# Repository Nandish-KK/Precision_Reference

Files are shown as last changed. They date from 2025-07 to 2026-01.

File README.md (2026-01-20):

#  2.5V Precision Reference

A compact 2.5V precision voltage reference module, ideal for use as a standalone reference when building analog circuit prototypes or for verifying the accuracy of your multimeter’s voltage range over time.

## Prototyping and Testing
The design required a low voltage source to make the Reference module as compact as possible. A CR2032 coin cell at 3V is the ideal candidate.
This requirement turns into a design constraint as the minimum operating voltage stated in the datasheet for the REF03 is 4.5V. The REF03 is a Low-Dropout
type Reference and is the best option to design a voltage reference due to its extremly low Temperature coefficient (10-50 ppm/C) and requires minimum passive components to operate.

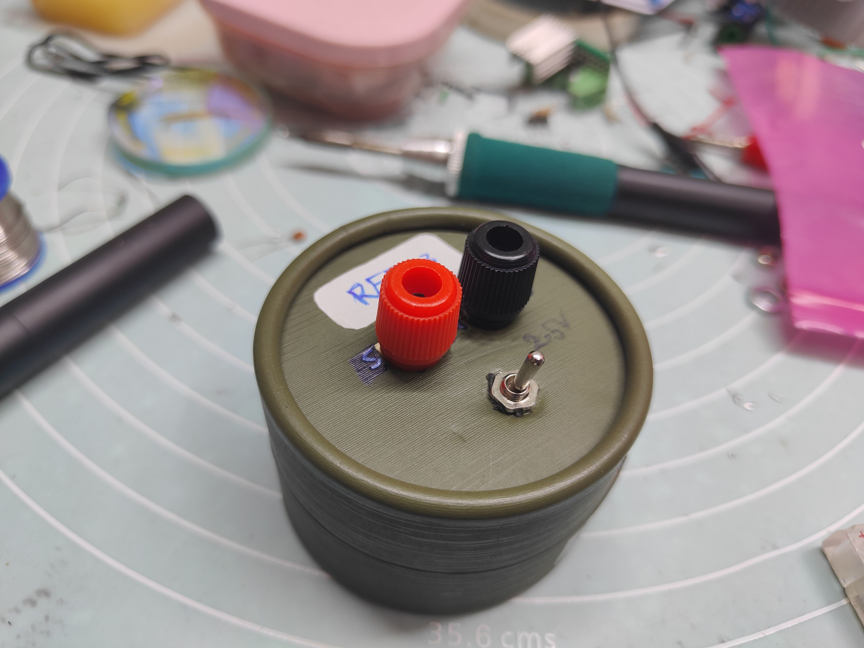
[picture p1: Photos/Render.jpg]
Prototype


Proto_board

### Charge pump
In order to generate a voltage that is sufficient to drive the REF03 above the minimum operating voltage a charge pump topology is implemented.
The charge pump consists of a variable frequency oscillator and a voltage doubler circuit. The oscillator is constructed using an SN74 logic inverter with
hysteresis and an RC feedback network. At 3V input, the circuit can generate a maximum of 5.6V but drops drastically depending on the load.
The quiescent current of the REF03 is around 1 mA, which also gives a bit of headroom to even sink some current into the DUT. 

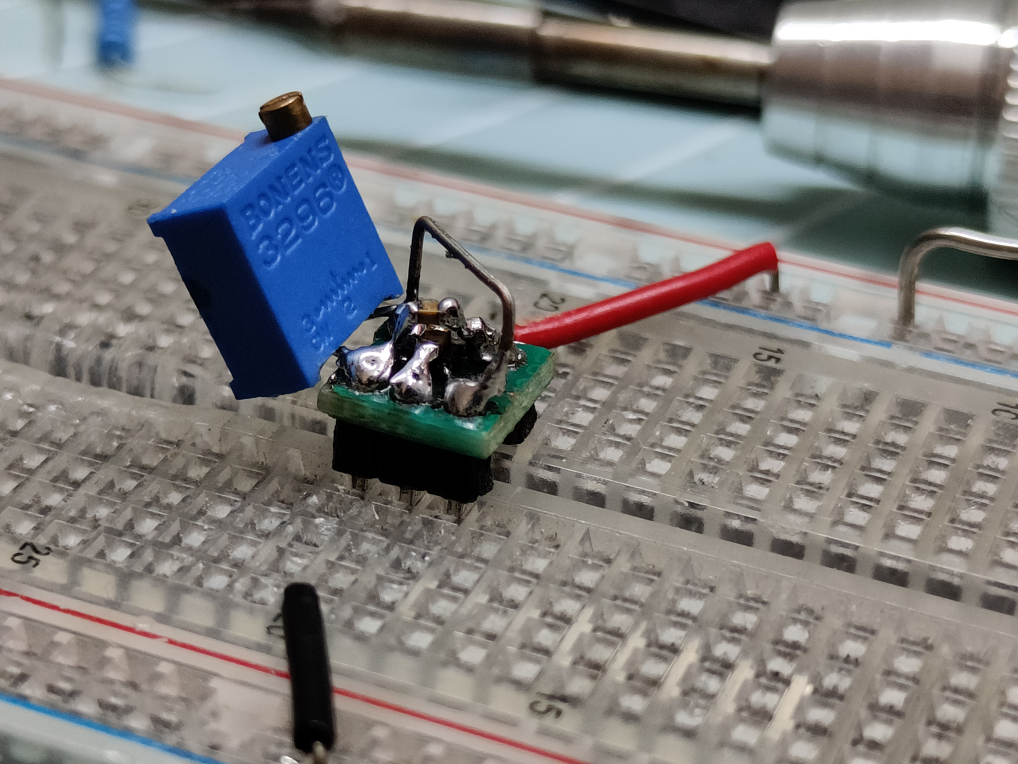
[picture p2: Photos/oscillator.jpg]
osc


Oscillator: SN74LVC2G14DBV sot23-6 soldered with passives on a proto pcb.

### Testing

The following tests are performed with a wide bandwidth. You can see some high-frequency noise along with voltage ripples at the charge pump output (with REF03 connected). After further testing, it seems like the ripples are generated from the oscillator.
The SN74LVC2G14DBV has a fast rising edge of about 4ns; this, combined with Schmitt trigger action and the board's parasitics, results in a ringing behavior at the output. This high-frequency component seems to bypass even the REF03 and appears at the reference voltage. Implementation of an additional filtering circuit might be necessary. Another option is to find an inverter with a slower rise time.

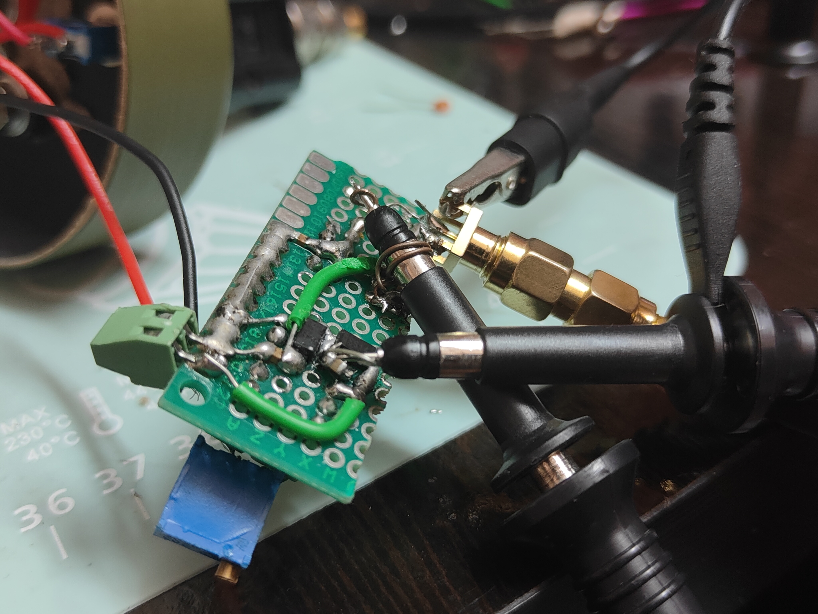
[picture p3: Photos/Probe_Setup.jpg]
probe_setup


Tested the reference output with coax to make sure the noise isn't from a background source. The other two channels are connected to the charge pump output and the oscillator output.

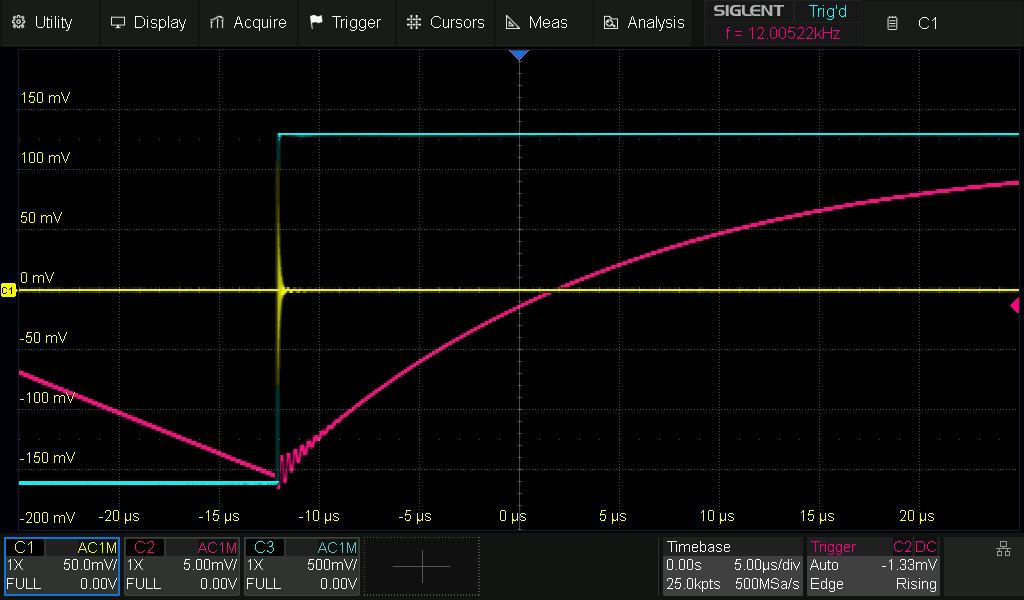
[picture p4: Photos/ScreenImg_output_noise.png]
High_frequency_Noise


- Yellow : Reference Output
- Pink :   Charge pump Output
- Blue :   Oscillator  Output

#### No Load condition

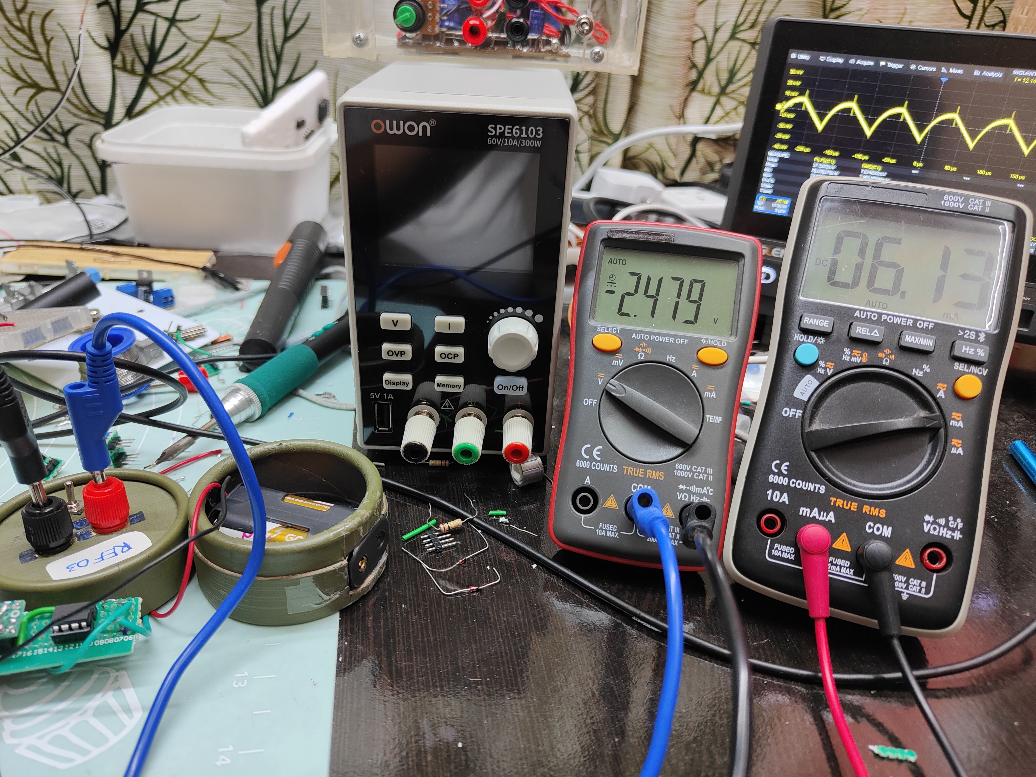
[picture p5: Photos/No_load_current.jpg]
Setup1

The voltmeter isn't accurate and is used to observe voltage drops with and without load.

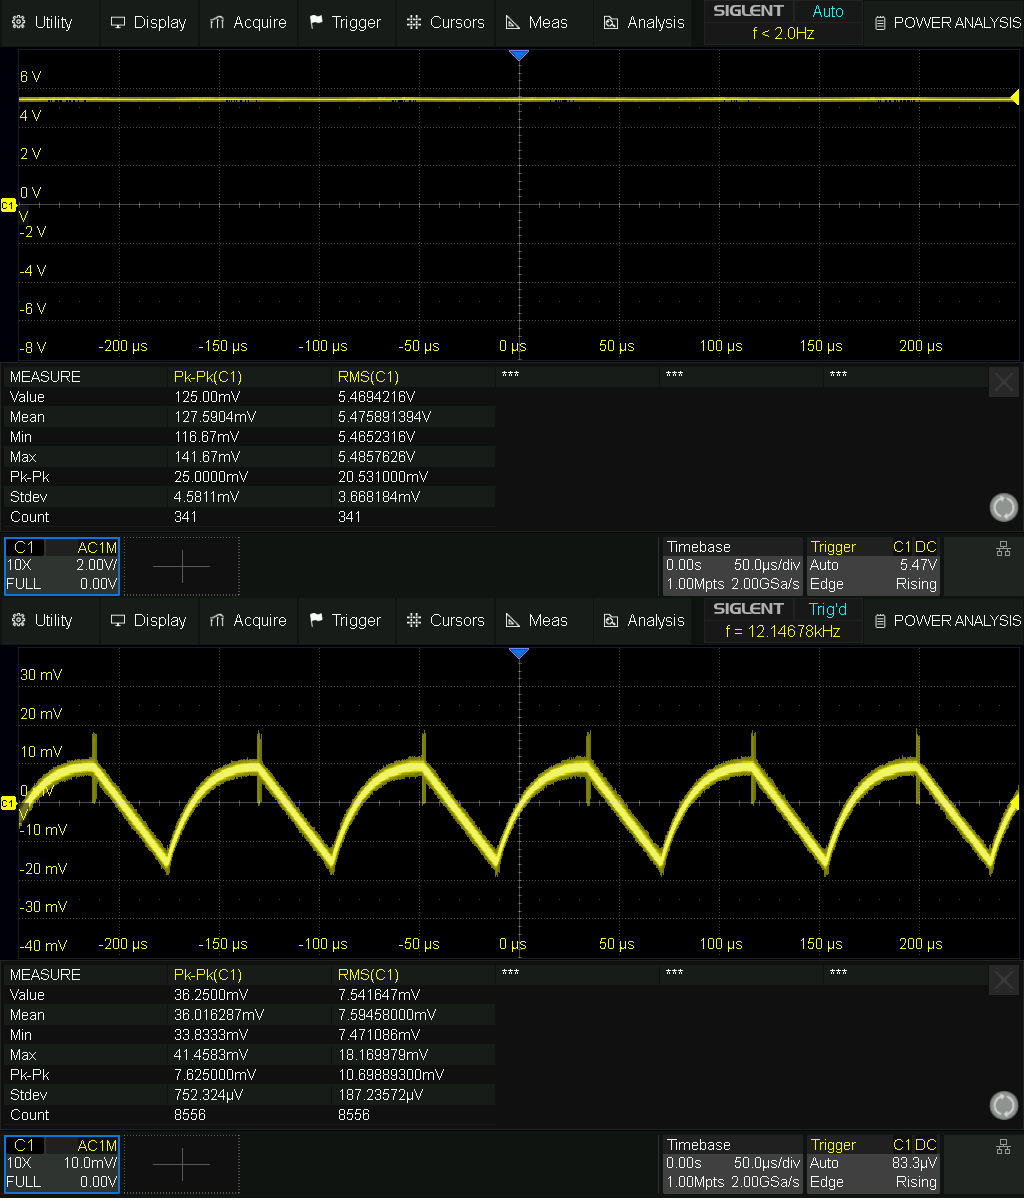
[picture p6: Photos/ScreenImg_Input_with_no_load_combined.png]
Charge_pump_out_no_load


With a high-impedance load like a multimeter (essentially no load) attached to the output of the REF03, the voltage is quite stable and exhibits minimal ripple.
The output voltage is around 5.47V with a ripple of 36.25mV peak-to-peak (7.54mV RMS). The setup also draws around 6mA, which is quite high. Since the REF03 draws 1-2 mA, the additional current should be consumed by the oscillator. This is not a good circuit to leave ON for a long time; it will drain the CR2032 in a day or two. Make sure to turn off the module with the toggle switch after use to prevent it from going completely dead. 

#### 10mA Load 
The charge pump output voltage seems to drop significantly if the REF03 starts to sink current to the load. The REF03 is rated to sink up to 24mA, but this much current will render my simple charge pump setup useless. I did end up testing the current sink capability of the prototype using a variable potentiometer, and it seems like the voltage starts to drop around 16mA of total current draw. This indicates that the prototype PCB was able to sink 10mA from the REF03 (remember that the circuit draws 6mA at idle). The voltage dropping trend was observed using a 3.5-digit multimeter, and results may vary with more accurate meters.

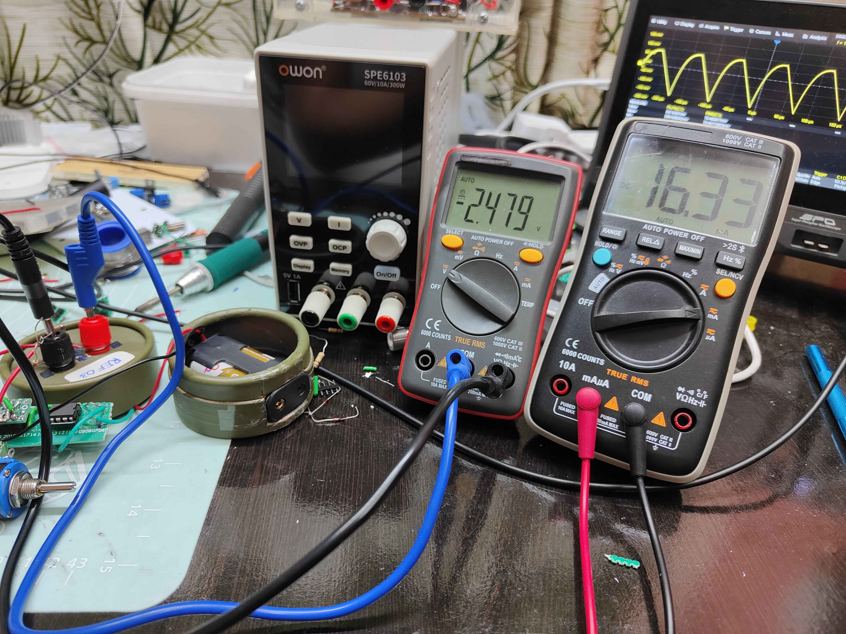
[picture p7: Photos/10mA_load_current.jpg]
Setup2

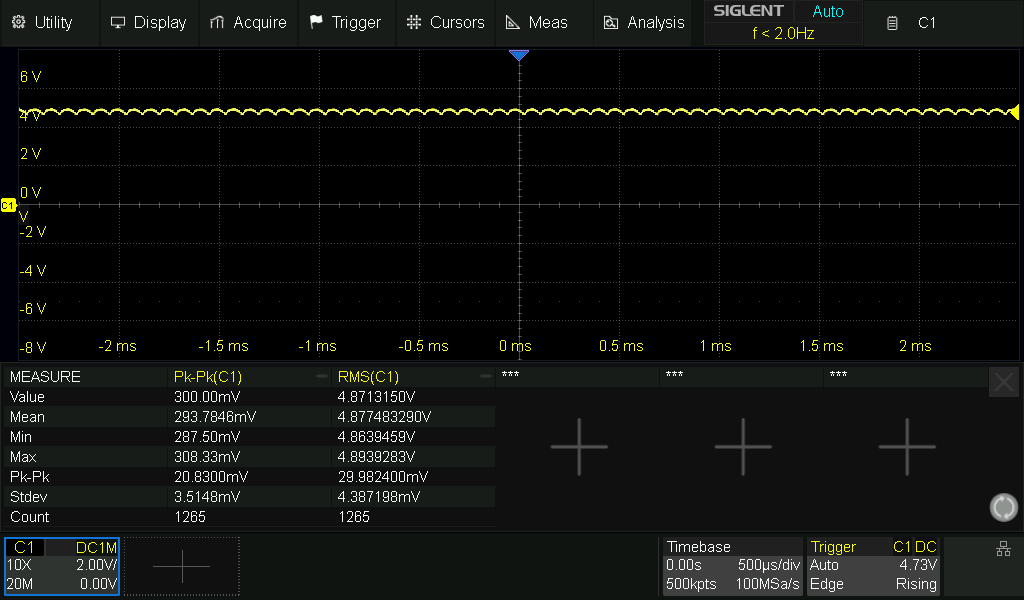
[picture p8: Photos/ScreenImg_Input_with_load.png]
Charge_pump_out_10ma_load


While sinking 16mA of total current, the charge pump output drops to around 4.87 volts while also exhibiting some ripple characteristics. The ripple is around 300mV peak-to-peak with a frequency that corresponds to the charge pump switching frequency. Thankfully, the ripple doesn't reflect on the output of the REF03. Note that these ripples can be minimized with appropriate capacitance.

## Output Stability

Currently, I don't own a precision multimeter, which makes it harder to measure how stable the output voltage really is. What I do own is a DSO with a 12-bit ADC (SDS800X), and it seems to read the voltage accurately up to 4 digits easily. The high-frequency noise at the output seems a bit annoying and likely skews the results a bit.

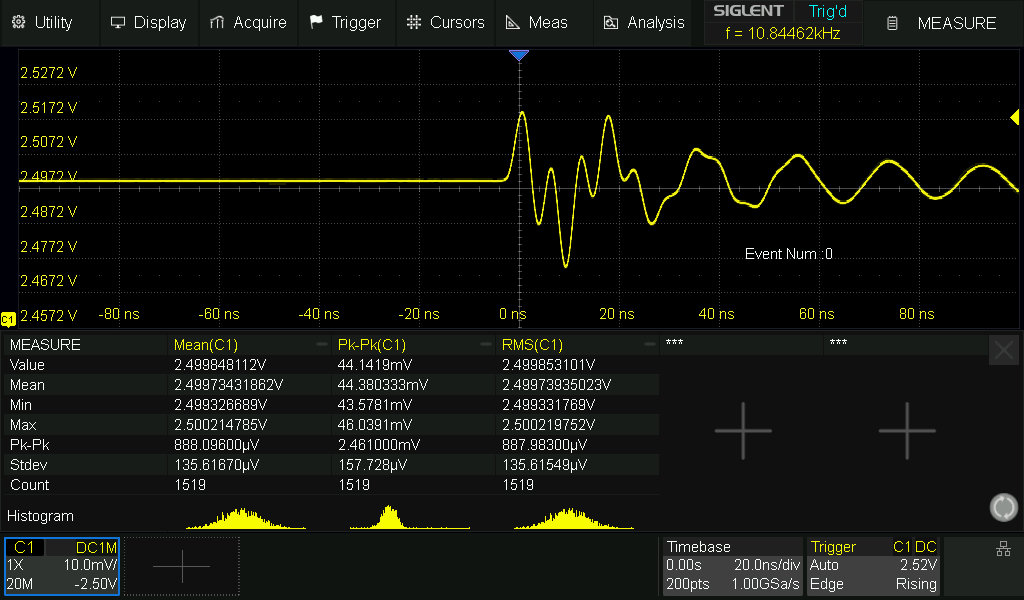
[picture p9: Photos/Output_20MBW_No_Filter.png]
Reference_stability

Reference voltage with No filter(Coupling: DC , BW: 20MHz)

## Filtering
In the end, I attempted to filter out the high-frequency noise using a simple RC filter with a cutoff frequency of around 1.5 kHz to achieve a more stable result. I also substituted the resistor with a ferrite bead. Both methods worked well in attenuating the noise. Although the filter did not eliminate it entirely, the noise was attenuated by approximately 20 dB when using the ferrite bead.

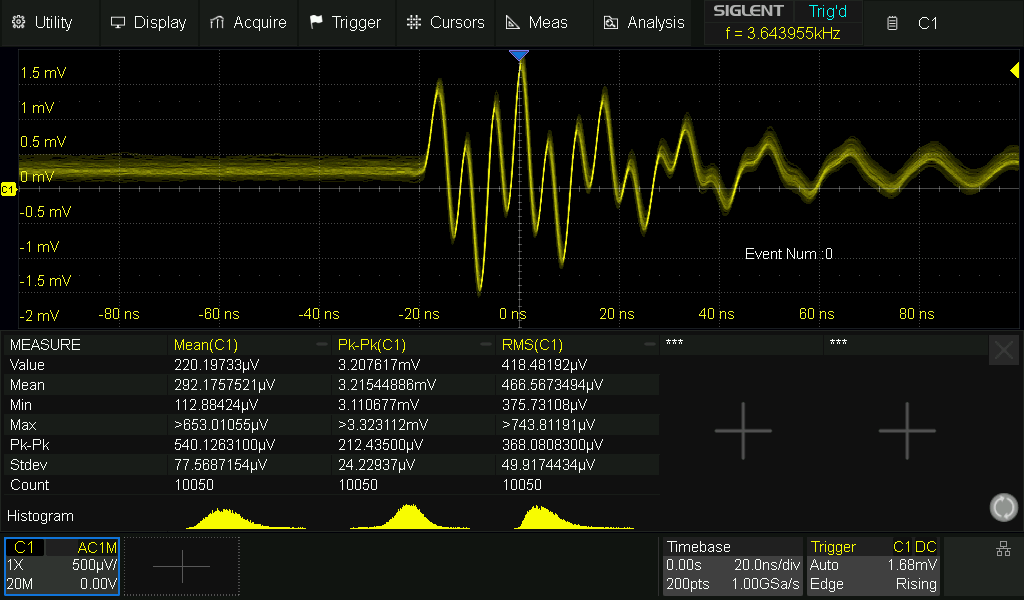
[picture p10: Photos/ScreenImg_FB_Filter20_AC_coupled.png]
Attenuated_Noise

Noise measurement with a Ferrite Bead Pi Filter (Coupling: AC , BW: 20MHz)

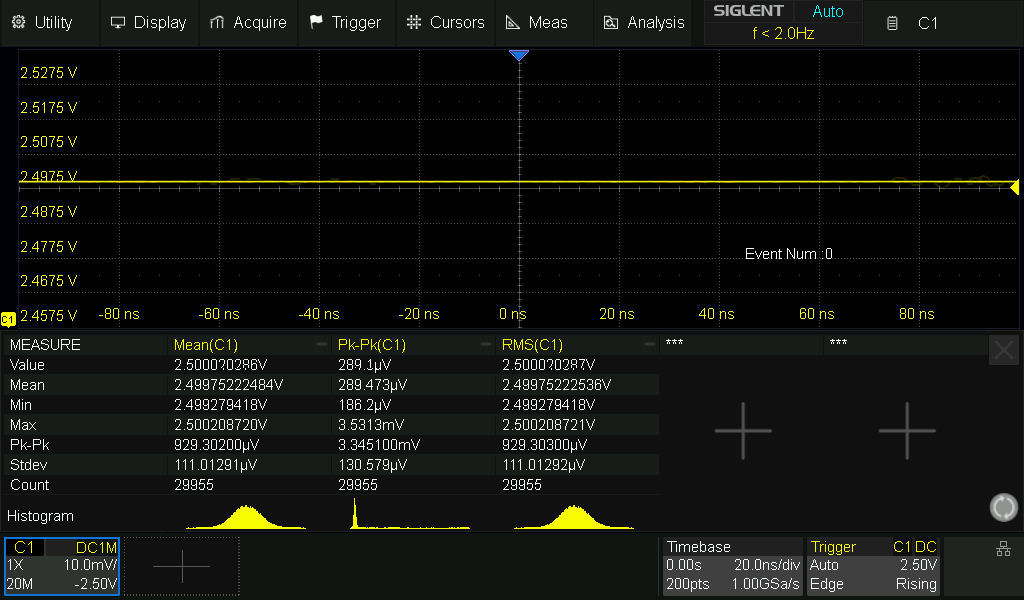
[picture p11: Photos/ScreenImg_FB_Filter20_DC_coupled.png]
Attenuated_Noise_DC

Reference voltage with Ferrite Bead and a 10uF capacitor filter(Coupling: DC , BW: 20MHz)

## PCB Layout
The following schematic and PCB are designed with KiCad 9.

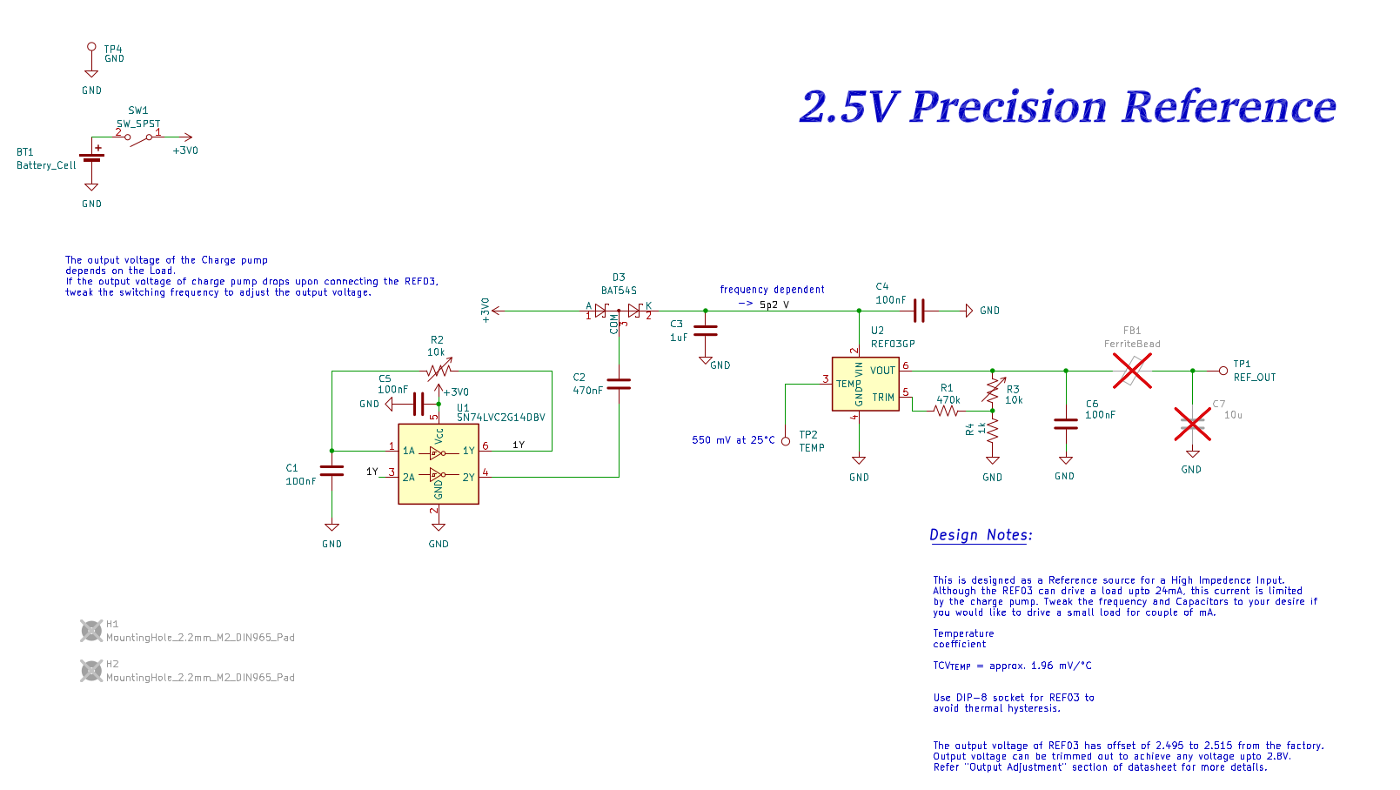
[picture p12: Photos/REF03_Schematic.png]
Schematic


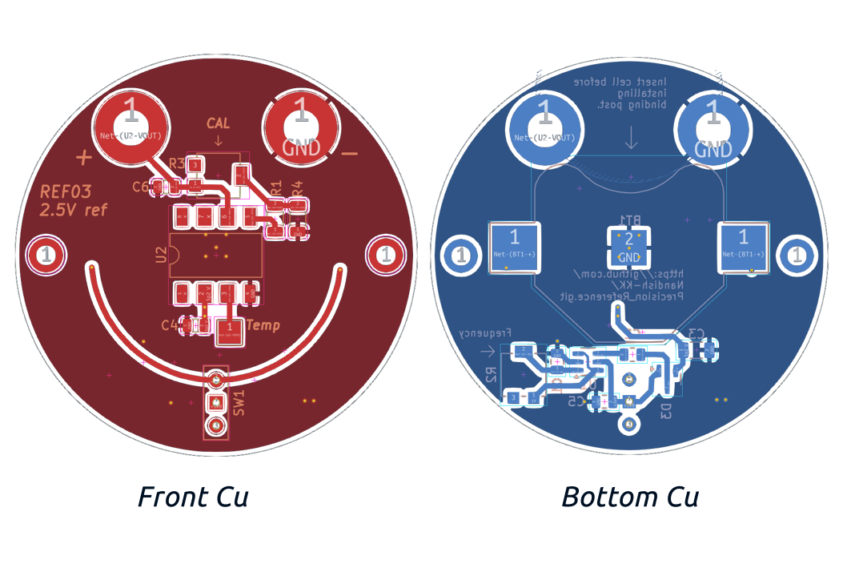
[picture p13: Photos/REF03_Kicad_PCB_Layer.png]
PCB


## Renders
- Tools:
  - pcb2blender addon for KiCad
  - Blender

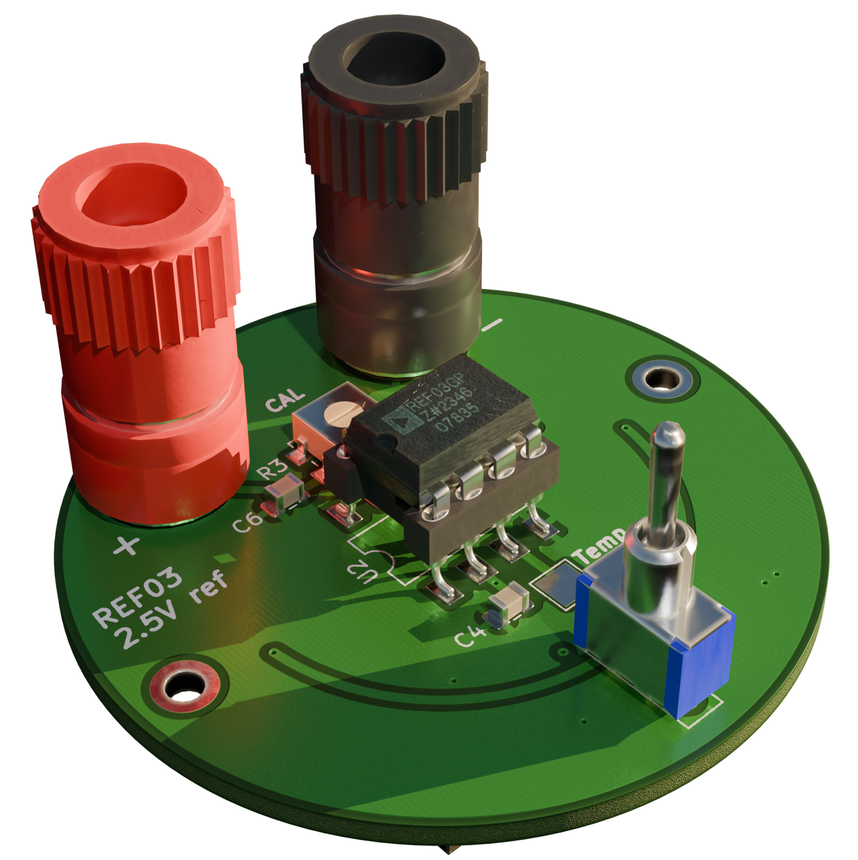
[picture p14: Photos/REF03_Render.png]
Render 1


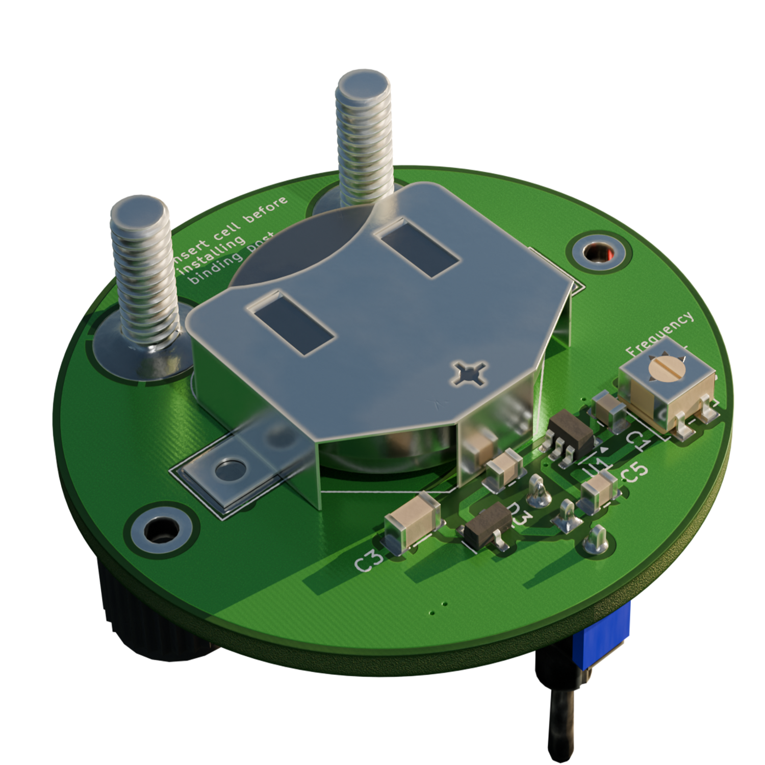
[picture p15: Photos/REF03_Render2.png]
Render 2


---
## Dimensions
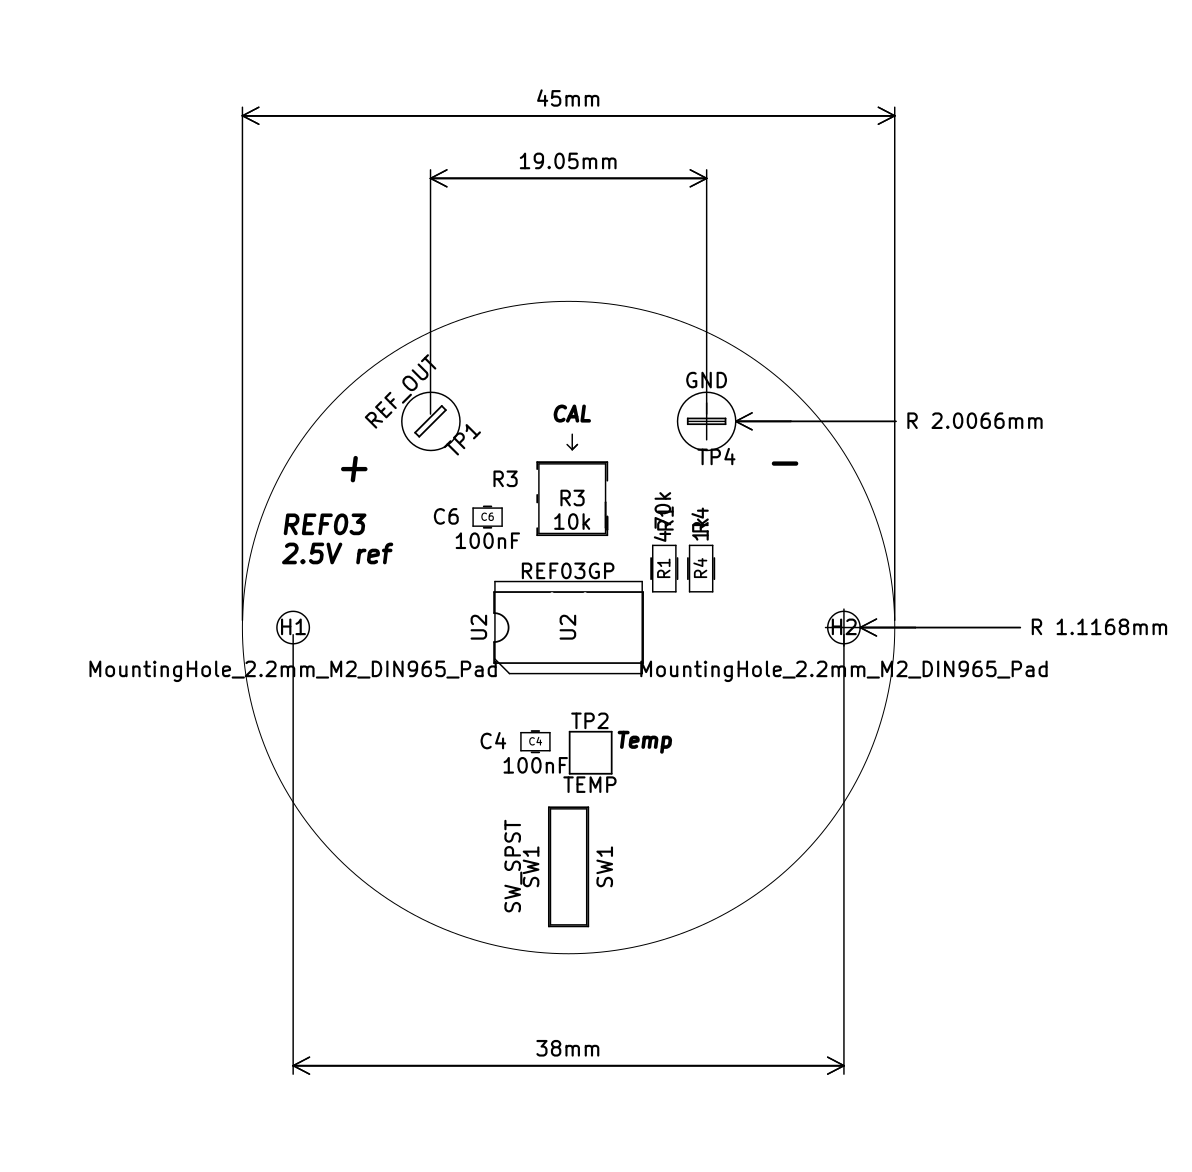
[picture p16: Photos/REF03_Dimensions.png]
Dimensions


- PCB Diameter: 45mm
- Binding Post Spacing: 19.05mm 
- Mounting Holes: 2.2mm

## PCB Features

- Single coin cell operation (CR2032).
- Trim pot for fine adjustment of output voltage.
- 4mm BNC terminal with 3/4" spacing.
- Adjustment range: 2.3V - 2.8V.
- Compact design with M2 mounting holes and toggle switch.

---

## Datasheet

Datasheet: [Precision 2.5V, 5.0V, and 10.0V Voltage References](https://www.analog.com/media/en/technical-documentation/data-sheets/ref01_02_03.pdf)

```plaintext

## Some Design Afterthought's

- The REF03 datasheet specifies a minimum operating voltage of 4.5 V.
- However, during testing, the output remained stable down to 3 V with no load.
- If your application sinks significant current, ensure the supply voltage remains well above the minimum — ideally with a low-voltage cutoff circuit.
- The current consumption is quite high for operating from a single cell. Needs further investigation of the charge pump circuit.
- Also, the toggle switch seems to be upside down... D'oh!

```

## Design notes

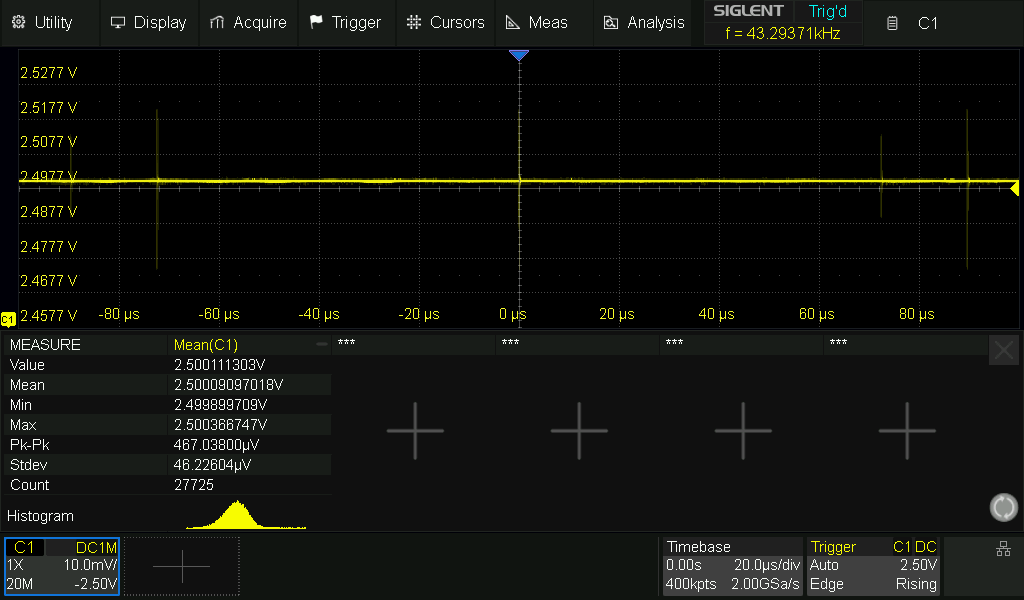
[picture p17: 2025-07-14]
Photos/Reference_output.png

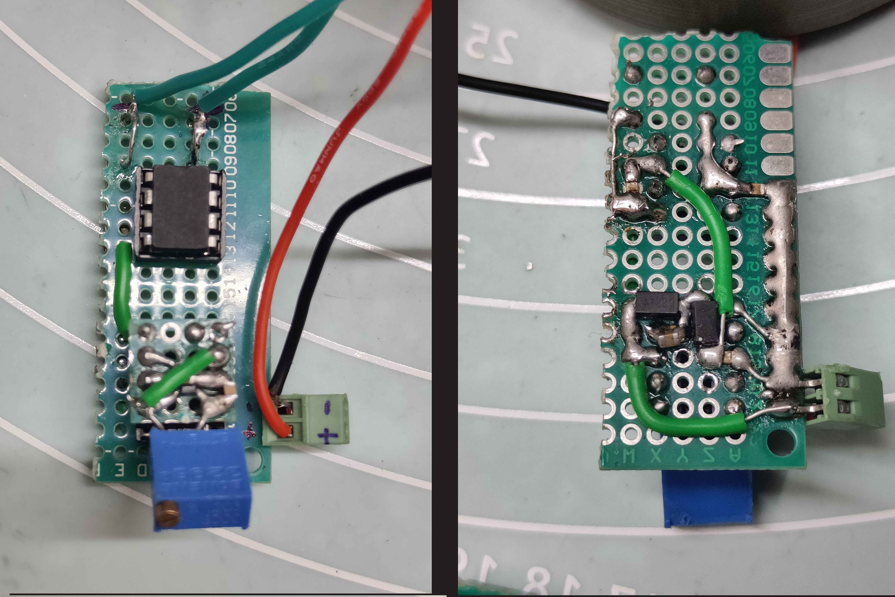
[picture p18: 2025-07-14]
Photos/proto_board_back.jpg

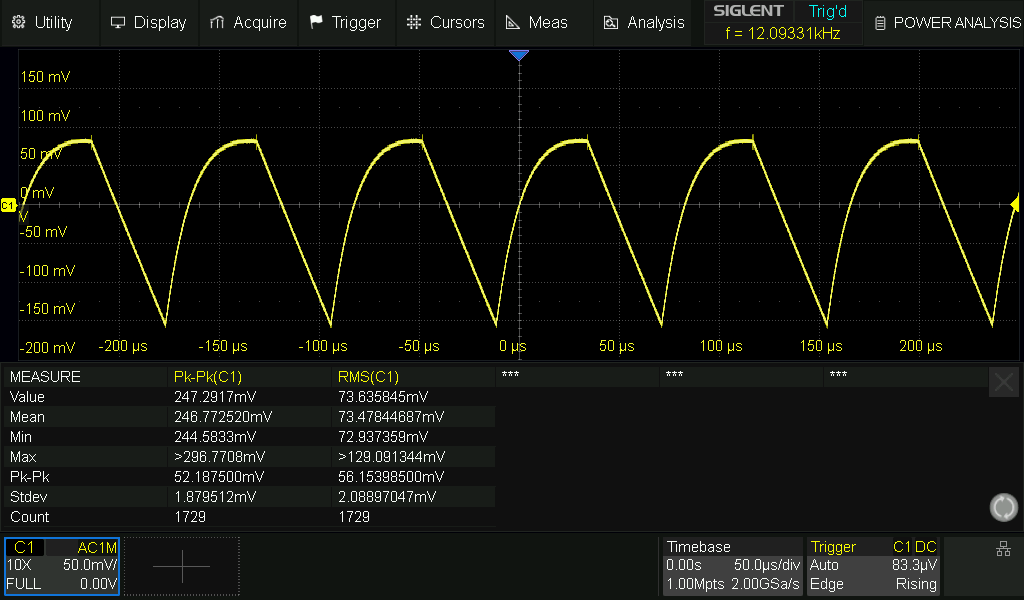
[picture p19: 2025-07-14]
Photos/ScreenImg_10ma_Sink.png

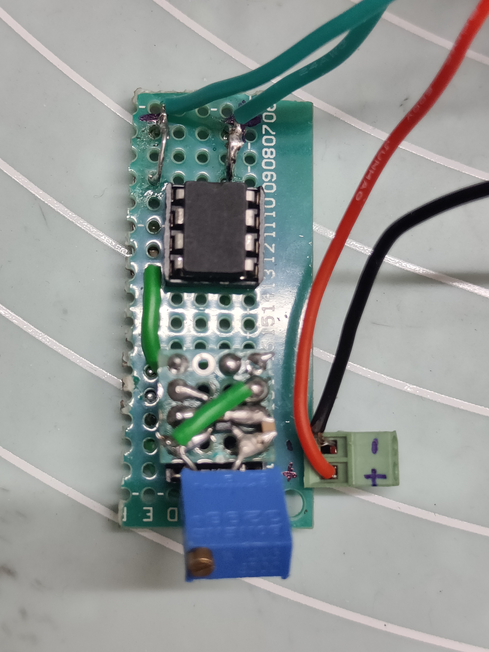
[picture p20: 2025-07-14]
Photos/proto_board_front.jpg

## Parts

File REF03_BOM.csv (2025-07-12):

Reference | Qty | Value | DNP | Exclude from BOM | Exclude from Board | Footprint | Datasheet
BT1 | 1 | Battery_Cell |  |  |  | Battery:BatteryHolder_Multicomp_BC-2001_1x2032 | ~
C1,C4,C5,C6 | 4 | 100nF |  |  |  | Capacitor_SMD:C_0805_2012Metric | ~
C2 | 1 | 470nF |  |  |  | Capacitor_SMD:C_0805_2012Metric | ~
C3 | 1 | 1uF |  |  |  | Capacitor_SMD:C_1206_3216Metric | ~
D3 | 1 | BAT54S |  |  |  | Package_TO_SOT_SMD:SOT-23 | https://www.diodes.com/assets/Datasheets/ds11005.pdf
R1 | 1 | 470k |  |  |  | Resistor_SMD:R_1206_3216Metric | ~
R2,R3 | 2 | 10k |  |  |  | Potentiometer_SMD:Potentiometer_Bourns_3214G_Horizontal | ~
R4 | 1 | 1k |  |  |  | Resistor_SMD:R_1206_3216Metric | ~
SW1 | 1 | SW_SPST |  |  |  | Button_Switch_THT:SW_Slide-03_Wuerth-WS-SLTV_10x2.5x6.4_P2.54mm | ~
TP1 | 1 | REF_OUT |  |  |  | TestPoint:TestPoint_Loop_D2.50mm_Drill1.0mm | ~
TP2 | 1 | TEMP |  |  |  | TestPoint:TestPoint_Pad_2.5x2.5mm | ~
TP4 | 1 | GND |  |  |  | TestPoint:TestPoint_Loop_D2.50mm_Drill1.0mm | ~
U1 | 1 | SN74LVC2G14DBV |  |  |  | Package_TO_SOT_SMD:SOT-23-6 | https://www.ti.com/lit/ds/symlink/sn74lvc2g14.pdf
U2 | 1 | REF03GP |  |  |  | Package_DIP:PowerIntegrations_SMD-8 | https://www.analog.com/media/en/technical-documentation/data-sheets/REF01_02_03.pdf

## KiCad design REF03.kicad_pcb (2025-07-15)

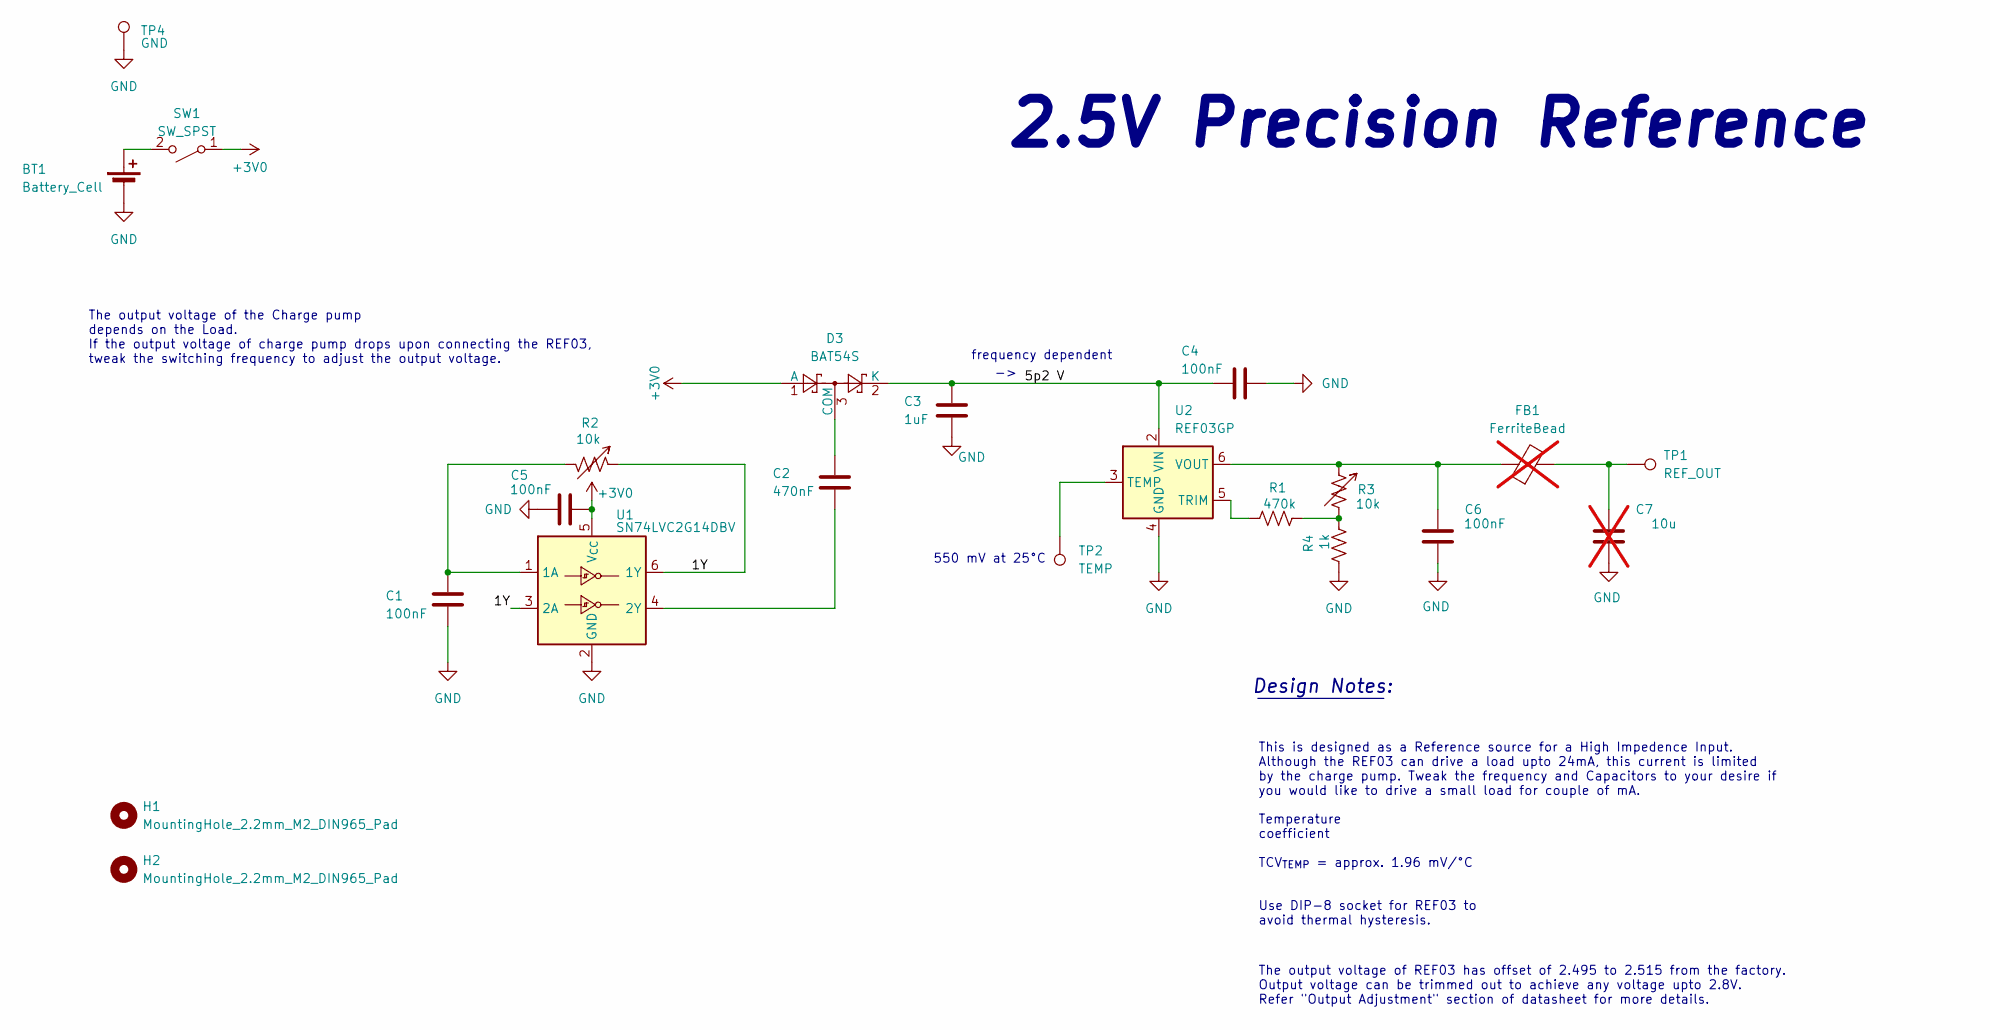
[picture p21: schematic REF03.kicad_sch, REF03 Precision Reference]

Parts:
BT1: Battery_Cell; BatteryHolder_Multicomp_BC-2001_1x2032
C1, C4, C5, C6: 100nF; C_0805_2012Metric
C2: 470nF; C_0805_2012Metric
C3: 1uF; C_1206_3216Metric
C7: 10u; C_0805_2012Metric; not fitted
D3: BAT54S; SOT-23
FB1: FerriteBead; L_0805_2012Metric; not fitted
H1, H2: MountingHole_2.2mm_M2_DIN965_Pad
R1: 470k; R_1206_3216Metric
R2, R3: 10k; Potentiometer_Bourns_3214G_Horizontal
R4: 1k; R_1206_3216Metric
SW1: SW_SPST; SW_Slide-03_Wuerth-WS-SLTV_10x2.5x6.4_P2.54mm
TP1: REF_OUT; TestPoint_Loop_D2.50mm_Drill1.0mm
TP2: TEMP; TestPoint_Pad_2.5x2.5mm
TP4: GND; TestPoint_Loop_D2.50mm_Drill1.0mm
U1: SN74LVC2G14DBV; SOT-23-6
U2: REF03GP; PowerIntegrations_SMD-8

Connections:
+3V0: C5.2, D3.1 (A), SW1.1 (A), U1.5 (V_{CC})
/1Y: R2.1, U1.3 (2A), U1.6 (1Y)
/5p2 V: C3.1, C4.2, D3.2 (K), U2.2 (VIN)
GND: BT1.2 (-), C1.2, C3.2, C4.1, C5.1, C6.1, C7.1, R4.1, TP4.1, U1.2 (GND), U2.4 (GND)
unnamed: BT1.1 (+), SW1.2 (B)
unnamed: C7.2, FB1.2, TP1.1
unnamed: C2.1, D3.3 (COM)
unnamed: R1.2, R3.2, R4.2
unnamed: C1.1, R2.2, U1.1 (1A)
unnamed: C2.2, U1.4 (2Y)
unnamed: TP2.1, U2.3 (TEMP)
unnamed: R1.1, U2.5 (TRIM)
unnamed: C6.2, FB1.1, R3.1, U2.6 (VOUT)

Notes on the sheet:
550 mV at 25°C
The output voltage of the Charge pump depends on the Load. If the output voltage of charge pump drops upon connecting the REF03, tweak the switching frequency to adjust the output voltage.
Design Notes:
2.5V Precision Reference
Use DIP-8 socket for REF03 to avoid thermal hysteresis.
Temperature coefficient TCV_{TEMP} = approx. 1.96 mV/°C
The output voltage of REF03 has offset of 2.495 to 2.515 from the factory. Output voltage can be trimmed out to achieve any voltage upto 2.8V. Refer "Output Adjustment" section of datasheet for more details.
This is designed as a Reference source for a High Impedence Input. Although the REF03 can drive a load upto 24mA, this current is limited by the charge pump. Tweak the frequency and Capacitors to your desire if you would like to drive a small load for couple of mA.
frequency dependent

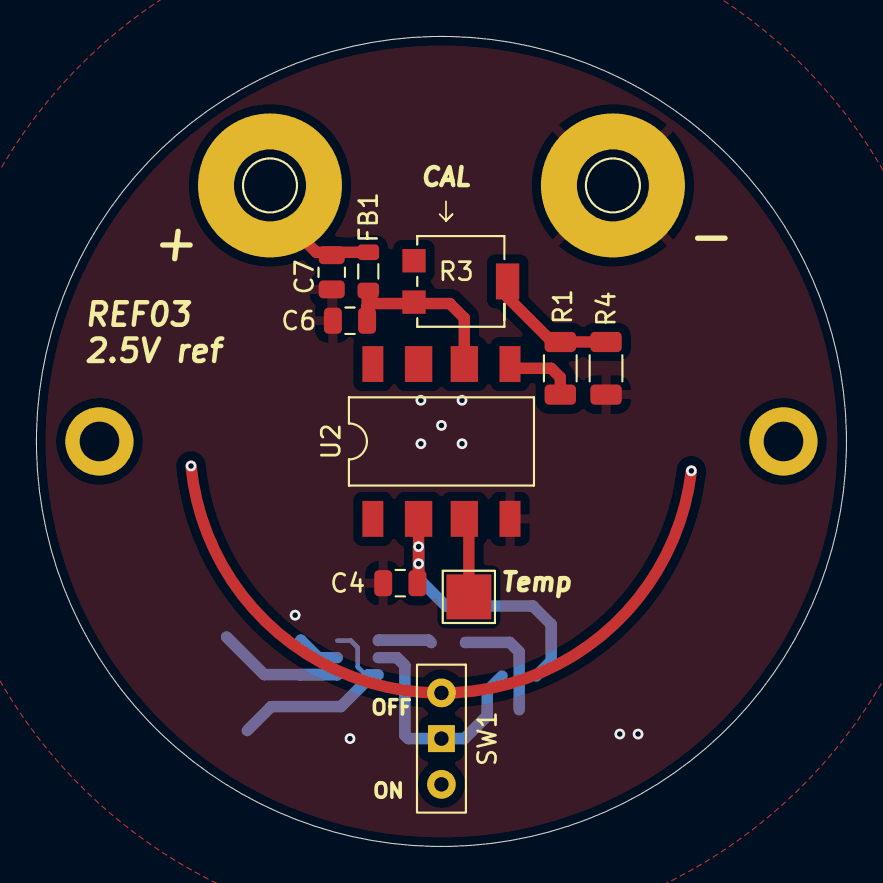
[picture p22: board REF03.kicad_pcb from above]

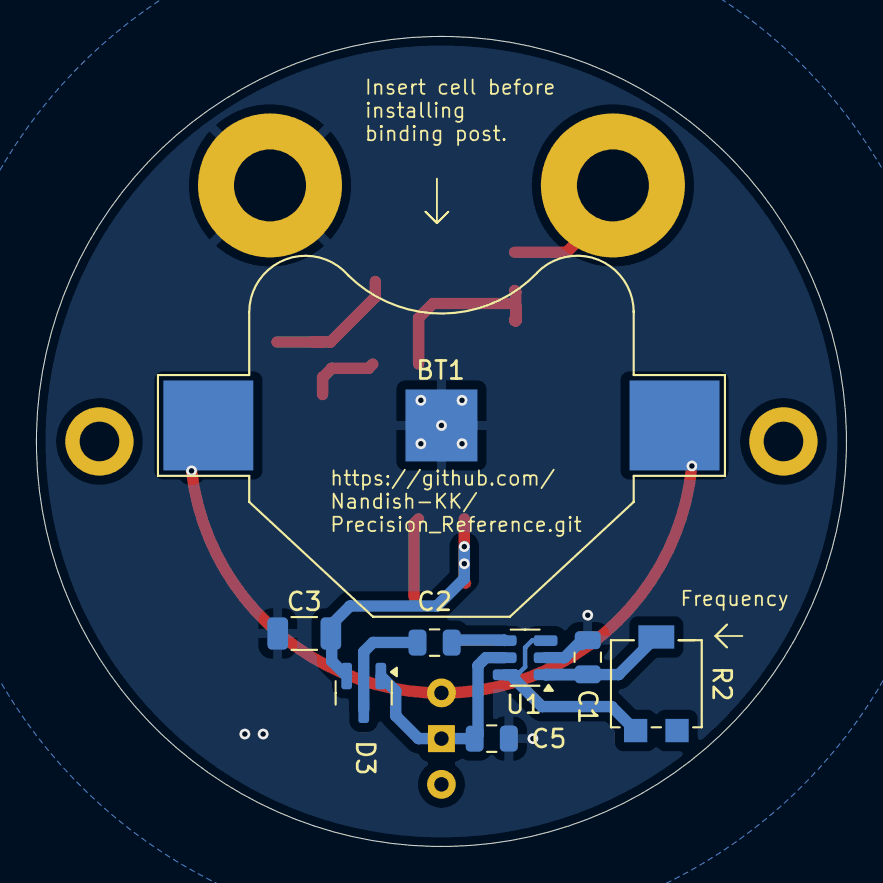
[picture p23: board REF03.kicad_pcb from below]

Board: 2 copper layers, 45.0 x 45.0 mm, 22 parts (8 on the bottom side), 13 nets.

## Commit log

2025-07-12 Added BOM, Dimensions
    [100SP1T1B4M2QE.step, 3000.step, BHX2-2032-SM.step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]
2025-07-14 Updated readme and added photos of the prototype
